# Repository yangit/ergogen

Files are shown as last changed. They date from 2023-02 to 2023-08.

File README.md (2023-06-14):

# Ergogen

```

REFFER to ./input/readme.md first!
REFFER to ./input/readme.md first!
REFFER to ./input/readme.md first!
REFFER to ./input/readme.md first!
REFFER to ./input/readme.md first!
REFFER to ./input/readme.md first!

```

***Ergonomic Keyboard Generator***

<br>



The project aims to provide a common configuration format to describe ***ergonomic*** 2D layouts and generate automatic plates, cases, as well as un-routed PCBs for them. The project grew out of (and is an integral part of) the [Absolem keyboard], and shares its [Discord] server as well.

<div align = center>
<br>
<br>
<br>

---

[][WebUI]
[][Documentation]
[][Discord]

---

</div>

<br>
<br>

## Getting Started

Until there's a proper "Getting started" guide, try getting acquainted with **Ergogen** by following these steps in order:

<br>

1. Read the **[Documentation]**.
    
    D'uuh.
    They're not complete by any measure, but should give you a fairly good idea what you're dealing with here.

    <br>
    
2. Try one of the web-based deployments.

    [][WebUI]   
    [][Unofficial]
   
    The unofficial deployment is probably better, tbh, and will soon be replacing the official one.
    Choose either one, then click things, look at outputs and see if things start to make sense.
   
    There is no need for you to download the **CLI** unless you want to do one of the following:
   
    - Preview in-development features
    - Use custom modifications
    - Contribute code
   
    <br>

3. Search the [`ergogen`][Topic] topic on GitHub.

    There, you can look at (and reverse engineer) a variety of real life configs using **Ergogen**.
    Pop them into the web UI to see what they do, tinker with them and things should start to make more sense.

    <br>

4. If a question persists after all of the above, feel free to ask it over on **[Discord]** and we'll do our best to help you out.

<br>

## Contributions

Feature ideas, documentation improvements, examples, tests, or pull requests welcome!
Get in touch on our **[Discord]**, and we can definitely find something you can help with, if you'd like to.

<br>

<!----------------------------------------------------------------------------->

[Absolem keyboard]: https://zealot.hu/absolem
[Documentation]: https://docs.ergogen.xyz
[Discord]: http://discord.ergogen.xyz
[WebUI]: https://ergogen.xyz
[Unofficial]: https://ergogen.cache.works/
[Topic]: https://github.com/topics/ergogen

<!--------------------------------{ Buttons }---------------------------------->

[Button WebUI]: https://img.shields.io/badge/Deployment-37a779?style=for-the-badge&logoColor=white&logo=AppleArcade
[Button Unofficial]: https://img.shields.io/badge/Unofficial-yellow?style=for-the-badge
[Button Official]: https://img.shields.io/badge/Official-37a779?style=for-the-badge
[Button Documentation]: https://img.shields.io/badge/Documentation-1793D1?style=for-the-badge&logoColor=white&logo=GitBook
[Button Discord]: https://img.shields.io/badge/Discord-5865F2?style=for-the-badge&logoColor=white&logo=Discord

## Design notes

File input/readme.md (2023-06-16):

# Export

Do read comments in `./input/build.sh`

```bash
./input/build.sh
```

After you have executed the build command you need to prepare the files for JLCPCB.com
So you go into `./output/*` and for every folder you do the steps below:

**If the JLCPCB does not recognize .zip file then triple check all tracks next to holes and edgecuts**

- Open the `.kicad` file under the generated folder
- Run DRC
- Press "B" to fill zones
- Phabrication Output => gerber
- Select 'Gerber2' format on drill page
- Export drill, pos, gerber
- Create .zip of the entire folder contents

## Order on jlcpb

- upload .zip form the above step
- select color
- select assembly
- select bottom side

## New footprints

Are taken from EasyEda online IDE by JLCPCB
Than converted using [this](https://wokwi.com/tools/easyeda2kicad) tool
That guarantees that when we order parts SMT service they will solder it in correct direction

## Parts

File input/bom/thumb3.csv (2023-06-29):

Comment | Designator | Footprint | LCSC
DIODE | D1,D2,D3 | Yan:D_SOD-523 | C511874
JC | JC1 | Yan:JST_SH_SM05B-SRSS-TB_1x05-1MP_P1.00mm_Horizontal | C136657

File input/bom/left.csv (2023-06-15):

Comment | Designator | Footprint | LCSC
DIODE | D1,D2,D3,D4,D5,D6,D7,D8,D9,D10,D11,D12,D13,D14,D15,D16 | Yan:D_SOD-523 | C511874
JC | JC1 | Yan:JST_SH_SM05B-SRSS-TB_1x05-1MP_P1.00mm_Horizontal | C136657
JB | JB1 | Yan:JST_SH_SM02B-SRSS-TB_1x02-1MP_P1.00mm_Horizontal | C160402
SB | SB1 | Yan:b3u-1000P | C231329
SS | SS1 | Yan:Slide switch | C381097

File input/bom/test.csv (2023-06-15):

Comment | Designator | Footprint | LCSC
DIODE | D1,D2,D3,D4,D5,D6 | Yan:D_SOD-523 | C511874
JC | JC1,JC2,JC3,JC4 | Yan:JST_SH_SM05B-SRSS-TB_1x05-1MP_P1.00mm_Horizontal | C136657
JB | JB1,JB2,JB3,JB4 | Yan:JST_SH_SM02B-SRSS-TB_1x02-1MP_P1.00mm_Horizontal | C160402
SB | SB1,SB2,SB3,SB4 | Yan:b3u-1000P | C231329
SS | SS1,SS2,SS3,SS4 | Yan:Slide switch | C381097

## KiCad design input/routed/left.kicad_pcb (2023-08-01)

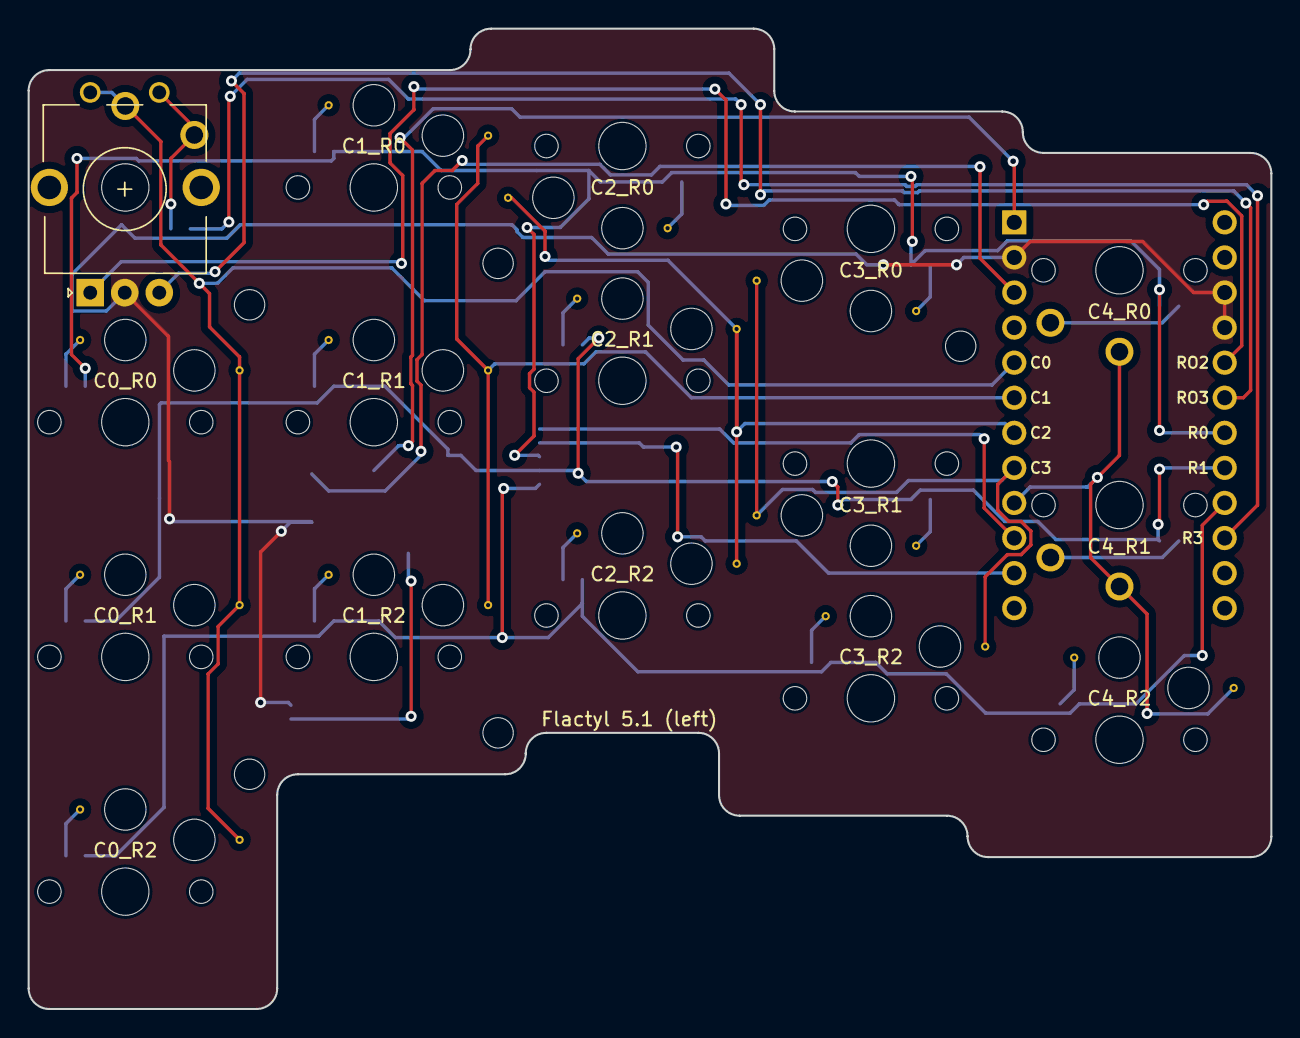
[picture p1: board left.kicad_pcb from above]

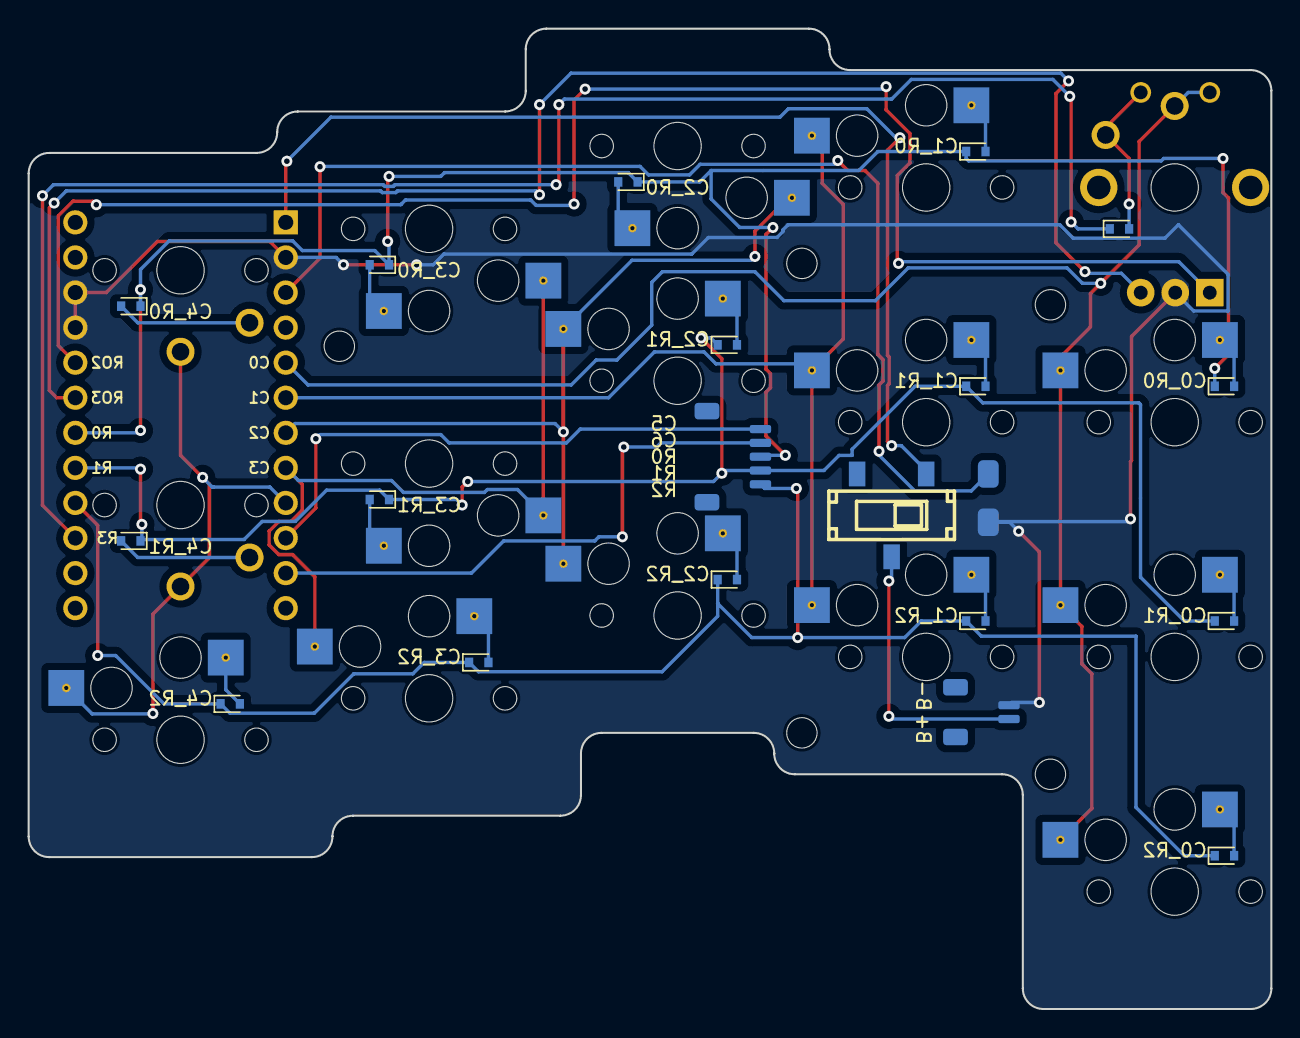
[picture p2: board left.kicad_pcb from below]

Board: 2 copper layers, 90.0 x 71.0 mm, 43 parts (36 on the bottom side), 33 nets.

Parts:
D1, D2, D3, D4, D5, D6, D7, D8, D9, D10, D11, D12, D13, D14, D15, D16: D_SOD-523
H1, H2, H3, H4, H5: MountingHole_2.2mm_M2
JB1: JST_SH_SM02B-SRSS-TB_1x02-1MP_P1.00mm_Horizontal
JC1: JST_SH_SM05B-SRSS-TB_1x05-1MP_P1.00mm_Horizontal
MCU1: NiceNano
ROT1: rotary_encoder
S1, S2, S3, S4, S5, S6, S7, S8, S9, S10, S11, S12, S13, S14, S15: Kailh_socket_PG1350_no_silk
SB1: b3u-1000P
SS1: SW-SMD_SS-3235D-03-L2.00
T1: Flactyl 5.1 (left); somelogo

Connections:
BSLI: JB1.2, SS1.2
C0: MCU1.5, ROT1.1, ROT1.2, S3.2, S3.4, S4.2, S4.4, S5.2, S5.4
C0_R0D: D4.2, S3.1, S3.3
C0_R1D: D5.2, S4.1, S4.3
C0_R2D: D6.2, S5.1, S5.3
C0_R3D: D3.2, ROT1.1, ROT1.2
C1: MCU1.6, S6.2, S6.4, S7.2, S7.4, S8.2, S8.4
C1_R0D: D7.2, S6.1, S6.3
C1_R1D: D8.2, S7.1, S7.3
C1_R2D: D9.2, S8.1, S8.3
C2: MCU1.7, S9.2, S9.4, S10.2, S10.4, S11.2, S11.4
C2_R0D: D10.2, S9.1, S9.3
C2_R1D: D11.2, S10.1, S10.3
C2_R2D: D12.2, S11.1, S11.3
C3: MCU1.8, S12.2, S12.4, S13.2, S13.4, S14.2, S14.4
C3_R0D: D13.2, S12.1, S12.3
C3_R1D: D14.2, S13.1, S13.3
C3_R2D: D15.2, S14.1, S14.3
C4: MCU1.9, S1.2, S2.2, S15.2, S15.4
C4_R0D: D1.2, S1.1
C4_R1D: D2.2, S2.1
C4_R2D: D16.2, S15.1, S15.3
C5: JC1.1, MCU1.10
C6: JC1.2, MCU1.11
GND: JB1.1, MCU1.2, MCU1.15, MCU1.16, ROT1.C, SB1.1
P2: MCU1.17, ROT1.A
P3: MCU1.18, ROT1.B
R0: D1.1, D4.1, D7.1, D10.1, D13.1, JC1.3, MCU1.19
R1: D2.1, D5.1, D8.1, D11.1, D14.1, JC1.4, MCU1.20
R2: D6.1, D9.1, D12.1, D15.1, D16.1, JC1.5, MCU1.21
R3: D3.1, MCU1.22
RAW: MCU1.1, SS1.1
RST: MCU1.3, SB1.2

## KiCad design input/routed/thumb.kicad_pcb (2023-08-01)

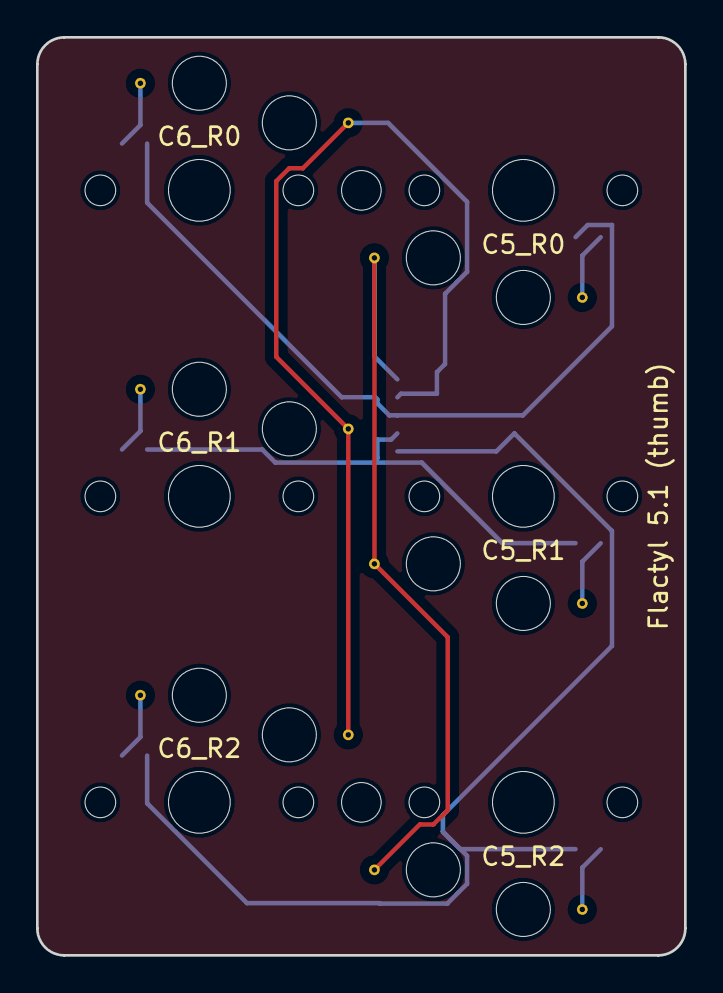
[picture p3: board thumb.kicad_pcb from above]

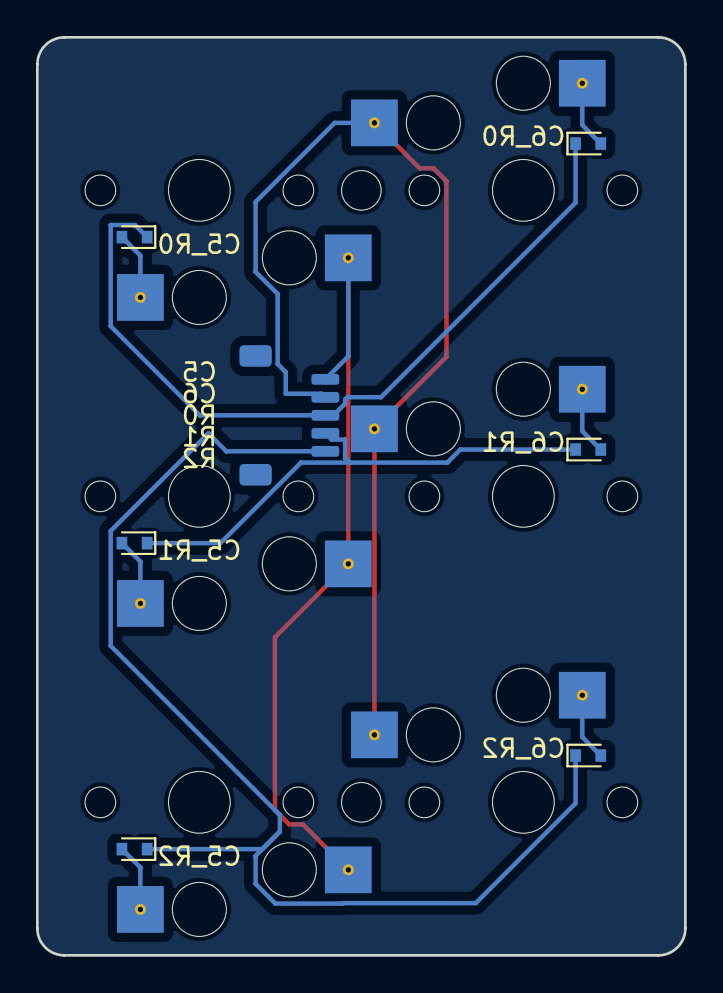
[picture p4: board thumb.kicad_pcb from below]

Board: 2 copper layers, 36.0 x 51.0 mm, 18 parts (13 on the bottom side), 11 nets.

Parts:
D1, D2, D3, D4, D5, D6: D_SOD-523
H1, H2: MountingHole_2.2mm_M2
JC1: JST_SH_SM05B-SRSS-TB_1x05-1MP_P1.00mm_Horizontal
S1, S2, S3, S4, S5, S6: Kailh_socket_PG1350_no_silk
T1: Flactyl 5.1 (thumb); somelogo
T2: x; somelogo
T3: y; somelogo

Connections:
C5: JC1.1, S1.2, S1.4, S2.2, S2.4, S3.2, S3.4
C5_R0D: D1.2, S1.1, S1.3
C5_R1D: D2.2, S2.1, S2.3
C5_R2D: D3.2, S3.1, S3.3
C6: JC1.2, S4.2, S4.4, S5.2, S5.4, S6.2, S6.4
C6_R0D: D4.2, S4.1, S4.3
C6_R1D: D5.2, S5.1, S5.3
C6_R2D: D6.2, S6.1, S6.3
R0: D1.1, D4.1, JC1.3
R1: D2.1, D5.1, JC1.4
R2: D3.1, D6.1, JC1.5

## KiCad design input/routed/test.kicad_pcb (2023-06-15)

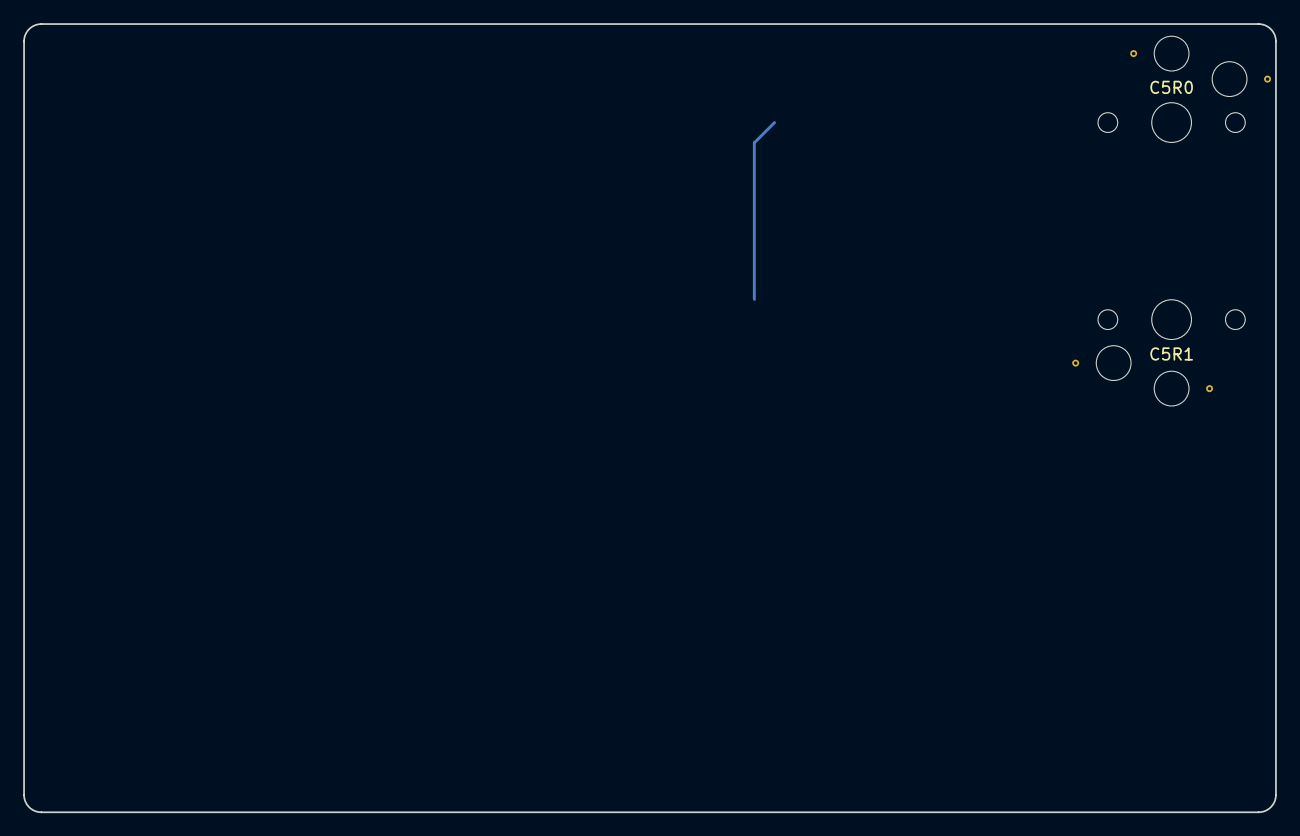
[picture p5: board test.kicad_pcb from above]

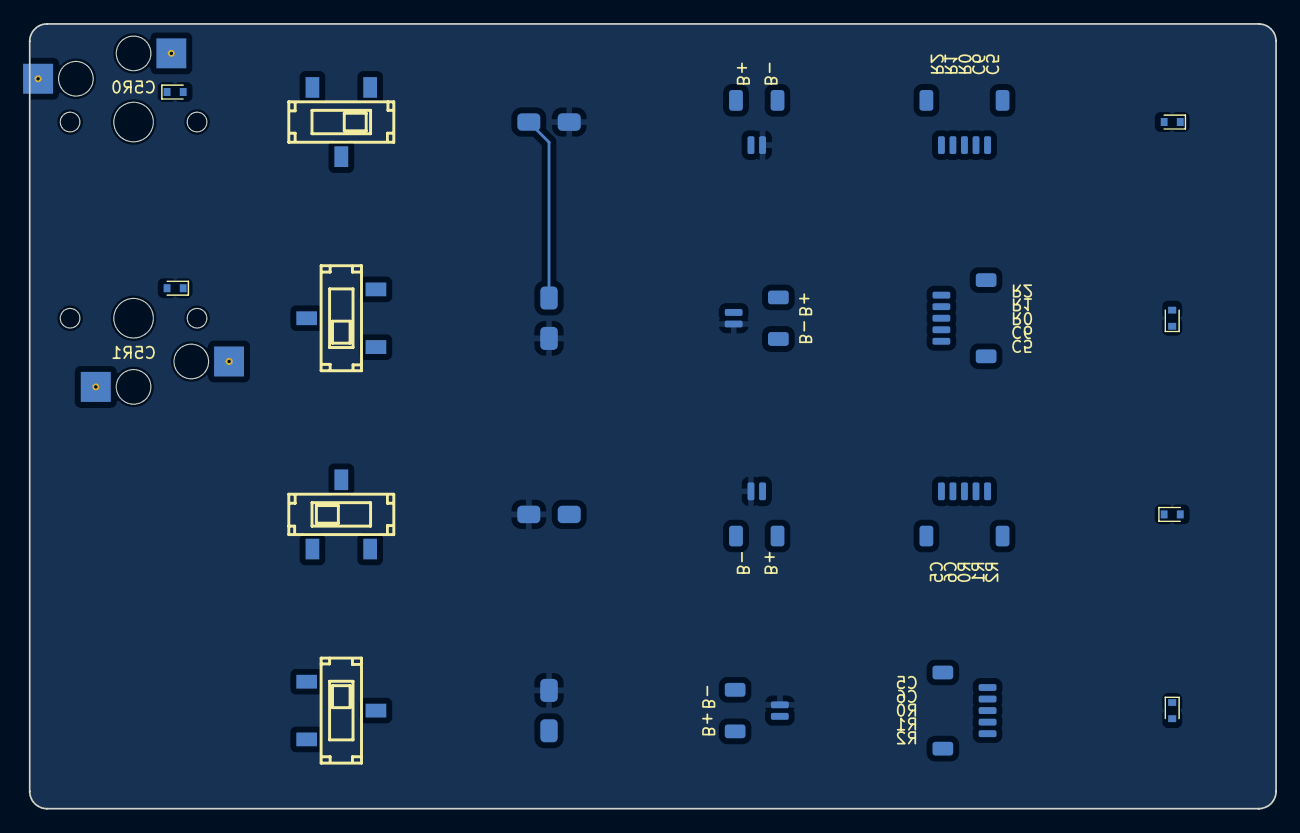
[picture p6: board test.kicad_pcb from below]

Board: 2 copper layers, 108.0 x 68.0 mm, 26 parts (24 on the bottom side), 14 nets.

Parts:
D1, D2, D3, D4, D5, D6: D_SOD-523
JB1, JB2, JB3, JB4: JST_SH_SM02B-SRSS-TB_1x02-1MP_P1.00mm_Horizontal
JC1, JC2, JC3, JC4: JST_SH_SM05B-SRSS-TB_1x05-1MP_P1.00mm_Horizontal
S1, S2: Kailh_socket_PG1350_no_silk
SB1, SB2, SB3, SB4: b3u-1000P
SS1, SS2, SS3, SS4: SW-SMD_SS-3235D-03-L2.00
T1: x; somelogo
T2: y; somelogo

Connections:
BSLI: JB1.2, JB2.2, JB3.2, JB4.2, SS1.2, SS2.2, SS3.2, SS4.2
C5: JC1.1, JC2.1, JC3.1, JC4.1, S1.2, S1.4, S2.2, S2.4
C5R0D: D5.2, S1.1, S1.3
C5R1D: D6.2, S2.1, S2.3
C6: JC1.2, JC2.2, JC3.2, JC4.2
GND: JB1.1, JB2.1, JB3.1, JB4.1, SB1.1, SB2.1, SB3.1, SB4.1
R0: D5.1, JC1.3, JC2.3, JC3.3, JC4.3
R1: D6.1, JC1.4, JC2.4, JC3.4, JC4.4
R2: JC1.5, JC2.5, JC3.5, JC4.5
RAW: SS1.1, SS2.1, SS3.1, SS4.1
RST: SB1.2, SB2.2, SB3.2, SB4.2
f: D1.2, D2.2, D3.2, D4.2
t: D1.1, D2.1, D3.1, D4.1
three: SS1.3, SS2.3, SS3.3

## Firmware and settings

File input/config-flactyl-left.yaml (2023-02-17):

units:
  choc_cap_x: 17.5
  choc_cap_y: 16.5
  stagger_ring: cy
  stagger_middle: 3
  stagger_index: -6
  stagger_index2: -3
  slider_offset: 3
  smdbutton_offset_x: 'cx/2-1'
  smdbutton_offset_y: -1.5
  nnano_offset: -10.5
  diode_x: 3.6
  diode_y: -2.6
  jst5offset: 8
  pinky_cut: '2-cx'
  logox: -2.5
  screw_ext_x: cx/2
  nnano_y: 33+3
  nnano_y_ext: 10
  nnano_ext_x_shift: 4.5
  nnano_x: 18+3
  mh_radius: 1.1
  connector_depth: 7
  connector_extension: 6  
  rR: 1 # will be -1 in right
  fR: 0 # will be 180 in right
points:  
  key:
    padding: cy
    spread: cx
  zones:
    main:
      rows:
        bottom:
        home:
        top:
      columns:
        pinky:
          rows:
            bottom:
            home:
            top:
            ttop:
        ring:
          key:
            stagger: stagger_ring
        middle:
          key:
            stagger: stagger_middle
        index:
          key:
            stagger: stagger_index
        index2:
          key:
            stagger: stagger_index2    
          
outlines:
  _nnano_ext:
    - what: rectangle
      where: 
        ref: main_index2_home
        shift: [nnano_ext_x_shift*rR,6.5+nnano_y_ext]
      size: [nnano_x, nnano_y+nnano_y_ext*2]
  _nnano:
    - what: rectangle
      where: 
        ref: main_index2_home
        shift: [0,6.5]
      size: [18+3, nnano_y]
  switch_cutouts:
    - what: rectangle
      where: true
      asym: source
      size: 14 # Plate cutouts are 14mm * 14mm for both MX and Choc
      bound: false
  keycaps:
    - what: rectangle
      where: true
      asym: source
      size: [choc_cap_x,choc_cap_y]
      bound: false
  _batt:
    - what: rectangle
      size: [connector_depth+connector_extension,7]
      where: 
        ref: main_ring_home
        shift: [connector_extension*rR/2, -5.5]          
  _connector_thumb:
    - what: rectangle
      size: [connector_depth+connector_extension,10]
      where: 
        ref: main_middle_bottom
        shift: [connector_extension*rR/2, -jst5offset]
  _mount_hole1:
    - what: circle      
      where:
        ref: main_pinky_bottom
        shift: [cx*rR/2,cy/2]
      radius: mh_radius
  _mount_hole2:
    - what: circle
      where:
        ref: main_pinky_top
        shift: [cx*rR/2,cy/2]
      radius: mh_radius
  _mount_hole3:
    - what: circle
      where:
        ref: main_middle_bottom
        shift: [-cx*rR/2,-cy/2]
      radius: mh_radius
  _mount_hole4:
    - what: circle
      where:
        ref: main_middle_top
        shift: [-cx*rR/2,-cy/2]
      radius: mh_radius
  _mount_hole5:
    - what: circle
      where:
        ref: main_index_bottom
        shift: [cx*rR/2,-cy/2]
      radius: mh_radius
  _mount_hole6:
    - what: circle
      where:
        ref: main_index_top
        shift: [cx*rR/2,cy/2-1.5]
      radius: mh_radius
  _screw_ext:
    - what: circle
      where: 
        ref: main_index_top
        shift: [screw_ext_x*rR,cy/2-1.5]
      radius: 3 
  _bottom_ext:
    - what: rectangle
      where: 
        ref: main_middle_bottom
        shift: [0,stagger_index+stagger_index2]
      size: [cx*3,cy]  
  _pinky_cut:
    - what: rectangle
      where:
        ref: main_pinky_home
        shift: [pinky_cut*rR,0]
      size: [cx,100]  
  _perimeter:
    - what: rectangle
      where: true
      asym: source
      size: [cx+4,cy]
  _pcb_outline_raw: [      
      _perimeter,  
      _screw_ext,    
      _bottom_ext,      
      -_pinky_cut,  
  ]          
  pcb_edgecut:
    - what: outline
      name: _pcb_outline_raw
      fillet: 1.4992  
  case: [      
    pcb_edgecut,    
    #-switch_cutouts,
    #-keycaps,
    -_nnano,
    -_nnano_ext,
    -_batt,
    -_connector_thumb,
    -_mount_hole1,
    -_mount_hole2,
    -_mount_hole3,
    -_mount_hole4,
    -_mount_hole5,
    -_mount_hole6        
  ]
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

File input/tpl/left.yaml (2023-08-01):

yanGenerator:
  holes:
    - ref: main_C3_R1
      shift: [(cx-5)*rR/2,cy/2]
    # - ref: main_C3_R2
    #   shift: [cx*rR/2,0]
    - ref: main_C2_R0
      shift: [-cx*rR/2,-cy/2]
    - ref: main_C2_R2
      shift: [-cx*rR/2,-cy/2]
    - ref: main_C0_R0
      shift: [cx*rR/2,cy/2]
    - ref: main_C0_R2
      shift: [cx*rR/2,cy/2]
  keys:
    - [C0_R0,true]
    - [C0_R1,true]
    - [C0_R2,true]

    - [C1_R0,true]
    - [C1_R1,true]
    - [C1_R2,true]

    - [C2_R0,false]
    - [C2_R1,true]
    - [C2_R2,true]

    - [C3_R0,false]
    - [C3_R1,false]
    - [C3_R2,true]

    - [C4_R2,true]

units:
  screw_nut_cutout: 3.1
  screw_nut_cutout_l: 7
  # choc_cap_x: 17.5
  # choc_cap_y: 16.5 
  choc_cap_x: 18
  choc_cap_y: 17
  stagger_ring: cy
  stagger_middle: 3
  stagger_index: -6
  stagger_index2: -3
  switchCutoutForPrint: 13.8

  batt_y_offset: -4
  batt_x_offset: -4

  slide_y_size: 12

  smdbutton_offset_x: '-cx/2+4.5'
  smdbutton_offset_y: '-cy/2+3'

  nnano_offset: -10.5
  diode_x: 3.6
  diode_y: -2.6

  jst5_y_offset: 5.50
  jst5_x_offset: -4
  pinky_cut: '2-cx'
  logox: 0.5
  screw_ext_x: cx/2
  nnano_y: 33+3
  nnano_y_ext: 5
  nnano_ext_x_shift: 0.5
  nnano_x: 18+3

  mh_radius: 1.1
  connector_depth: 7
  connector_extension: 8
  connector_thumb_width: 10
  rR: 1 # will be -1 in right
  fR: 0 # will be 180 in right
points:  
  key:
    padding: cy
    spread: cx
  zones:
    main:
      rows:
        R2: #bottom
        R1: #home
        R0: #top
      columns:
        C0: #pinky
          rows:
            R2: #bottom
            R1: #home
            R0: #top
            R3: #encoder
        C1: #ring
          key: 
            stagger: stagger_ring
        C2: #middle
          key:
            stagger: stagger_middle
        C3: #index
          key:
            stagger: stagger_index
        C4: #index2 
          key:
            stagger: stagger_index2  
outlines:
  _nnano_mount:
    - what: circle
      where:
        ref: main_C4_R1
        shift: [7.6, -7.5]
      radius: 1
  _nnano_ext:
    - what: rectangle
      where: 
        ref: main_C4_R1
        #shift: [0,6.5]
        shift: [nnano_ext_x_shift*rR,13]
      size: [nnano_x, nnano_y+nnano_y_ext*2]
  _nnano:
    - what: rectangle
      where: 
        ref: main_C4_R1
        shift: [0,8]
      size: [nnano_x, nnano_y]
  left_switch_cutouts:
    - what: rectangle
      where: true
      asym: source
      size: switchCutoutForPrint # Plate cutouts are 14mm * 14mm for both MX and Choc
      bound: false
  left_keycaps:
    - what: rectangle
      where: true
      asym: source
      size: [choc_cap_x,choc_cap_y]
      bound: false
  left_keycaps_round:
    - what: rectangle
      where: true
      asym: source
      size:
        - choc_cap_x-0.5
        - choc_cap_y-0.5
      bound: false
      fillet: 1.49
  _batt:
    - what: rectangle
      size: [connector_depth+connector_extension,7]
      where: 
        ref: main_C1_R2
        shift: [connector_extension*rR/2+batt_x_offset*rR, batt_y_offset]
  _slide:
    - what: rectangle
      size: [cx-2, slide_y_size]
      where: 
        ref: main_C1_R1
        shift: [0, -cy/2+slide_y_size/4]
  _connector_thumb:
    - what: rectangle
      size: [connector_depth+connector_extension, connector_thumb_width]
      where: 
        ref: main_C2_R1
        shift: [connector_extension*rR/2+jst5_x_offset*rR, -jst5_y_offset]
  # _lower_ext:
  #   - what: rectangle
  #     where: 
  #       ref: main_C2_R2
  #       shift: [0,stagger_index+stagger_index2]
  #     size: [cx*3,cy]  
  _pinky_cut:
    - what: rectangle
      where:
        ref: main_C0_R1
        shift: [pinky_cut*rR,0]
      size: [cx,100]  
  _perimeter:
    - what: rectangle
      where: true
      asym: source
      size: [cx+4,cy]
  _pcb_outline_raw: [      
      _perimeter,     
      -_pinky_cut,  
  ]          
  left_pcb_edgecut:
    - what: outline
      name: _pcb_outline_raw
      fillet: 1.49
  _pcb_outline_raw_with_keys:
    - _perimeter
    - '-_pinky_cut'
    - left_keycaps
  left_pcb_edgecut_with_keys:
    - what: outline
      name: _pcb_outline_raw_with_keys
      fillet: 1.49
  left_case: [      
    left_pcb_edgecut,    
    -_nnano_ext,
    -_batt,
    -_slide,
    -_connector_thumb,     
  ] 
  left_case_nano: [      
    left_pcb_edgecut,    
    -_nnano_mount,
  ]
  left_screw: [
    # left_pcb_edgecut,
  ]
  left_screw_holes: [
    _batt,
    _slide,
    _connector_thumb,
  ]
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

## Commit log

2023-02-15 Add build Add sane wire checker Add more components Add thumb config Add constants sanity check Make all footrpints one sided
2023-02-17 Copy tracks Fix footprint errors
    [thumb.kicad_pcb]
2023-02-17 Routing for left
    [left.kicad_pcb]
2023-02-17 right part is autogenerated
    [right.kicad_pcb]
2023-02-17 All is cool!
    [right.kicad_pcb]
2023-02-17 Fix rounting right
    [right.kicad_pcb]
2023-02-19 Auto bom,pos,drill,step
    [left.kicad_sch, right.kicad_sch, thumb.kicad_sch]
2023-02-19 Clean up build, soon will be jlcpcb
    [left.kicad_sch, right.kicad_sch]
2023-02-20 Footprints fixed for SMD
    [left.csv, right.csv, test.csv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]
2023-02-20 Add 4.1
    [left-B_Cu.gbr, left-B_Mask.gbr, left-B_Paste.gbr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]
2023-02-21 All SMP works fine
    [left_case.dxf, right_case.dxf, test.csv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]
2023-02-24 Screw cutouts generated
2023-05-30 move files
    [left-B_Cu.gbr, left-B_Mask.gbr, left-B_Paste.gbr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]
2023-05-30 add nineNano mount
2023-06-06 Better holes for case mount
2023-06-06 Remove screw
2023-06-06 Extend case keywell beyond keys
2023-06-07 add rotary encoder hole
2023-06-08 Update routed
    [left.kicad_pcb, right.kicad_pcb]
2023-06-13 Thumb connector move
    [thumb.kicad_pcb]
2023-06-13 Route thumb, bump version
    [thumb.kicad_pcb]
2023-06-13 Move slider and reset
    [left.yaml]
2023-06-14 top slider
    [left.csv, right.csv]
2023-06-14 Can solder button on rotary
2023-06-15 fix top slider
    [test.csv, test.kicad_pcb]
2023-06-15 Fix top slider bom
    [left.csv, right.csv, test.csv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]
2023-06-15 Routed left
    [left.kicad_pcb]
2023-06-15 V5 pcbs
    [left.kicad_pcb, right.kicad_pcb]
2023-06-16 Fix righnt
    [left.kicad_pcb, right.kicad_pcb]
2023-06-28 connector cutout
2023-06-29 move thumb cutout
    [thumb3.kicad_pcb]
2023-08-01 PCB 5.1
    [left.kicad_pcb, right.kicad_pcb, thumb.kicad_pcb]
